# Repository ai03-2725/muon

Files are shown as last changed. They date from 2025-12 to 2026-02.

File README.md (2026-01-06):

# muon
Minimal USB-C to JST-SH daughterboard PCBs

**Currently in development; not finalized or tested.**

## Variants

### Variant A (latest revision A2)
Narrow and wide variant
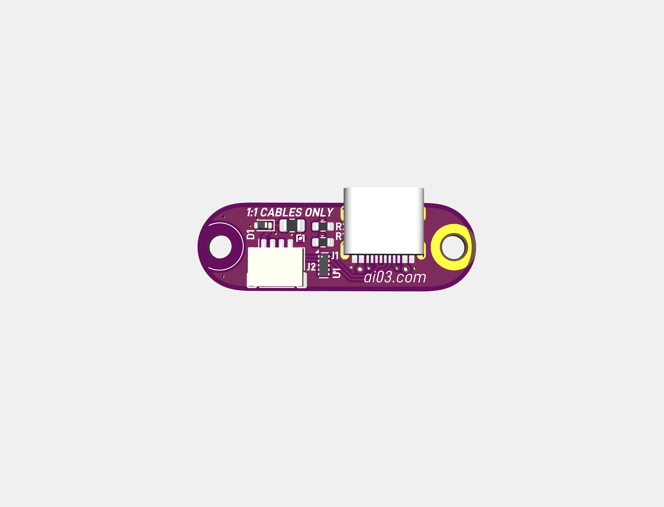
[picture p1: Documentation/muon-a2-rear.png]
Rear

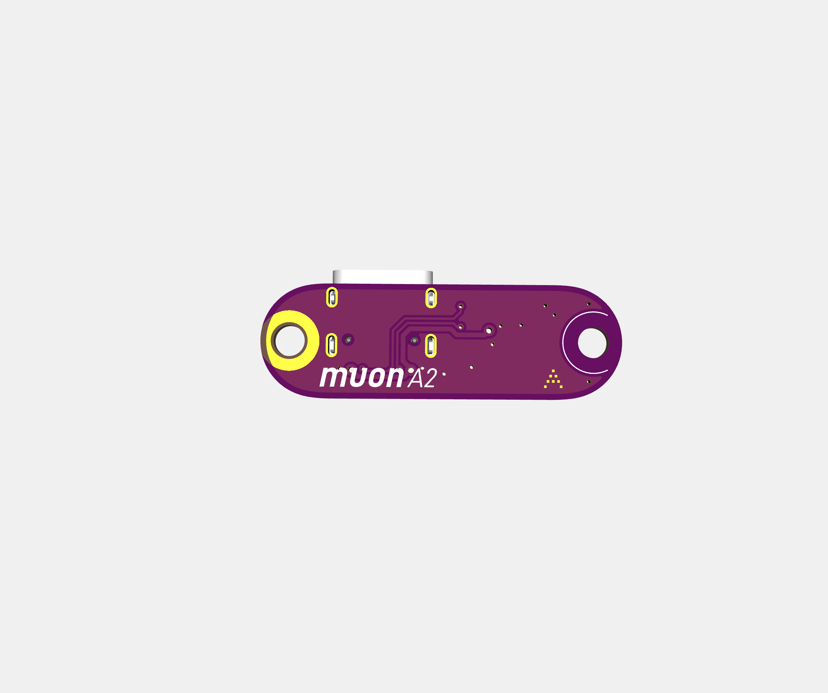
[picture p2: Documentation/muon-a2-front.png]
Front


### Variant B (latest revision B2)
Symmmetrical and rectangular variant
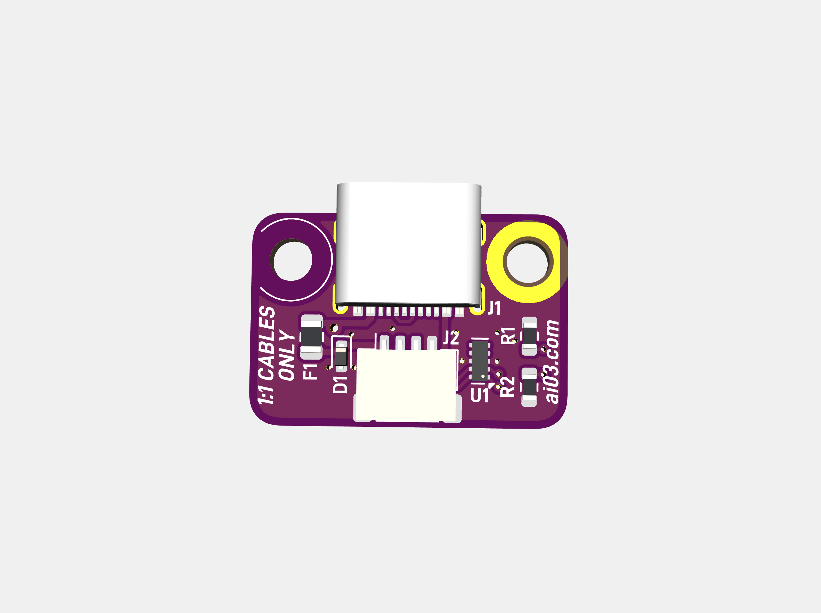
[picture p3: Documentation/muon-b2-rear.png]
Rear

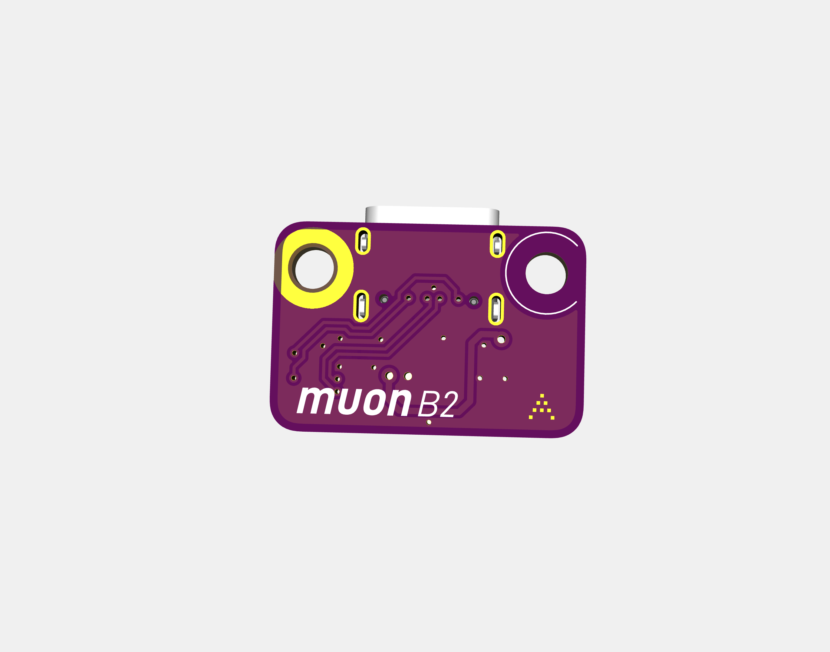
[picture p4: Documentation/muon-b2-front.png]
Front


## Features

- Physically compact
  - 31.50 x 10.00 mm for Variant A
  - 20.00 x 13.50 mm for Variant B
  - Balanced minimizing of dimensions with a focus on ease of implementation on the case-side
- Physically robust
  - 2x M2.5 screws for a balance between robustness, ease of manufacturing, user-friendliness, and physical compactness
  - 1.6mm PCB to counter cable torque and resist over-tensioned screw-in by users
- Minimal, practical implementation
  - Single-sided for easy assembly - whether at a factory or reflowing at home
  - Two-layer for affordable manufacturing
  - 3D printable solder paste stencil file included (0.2mm nozzle and line width, 0.08mm layer height)
  - Asymmetrical design with protruding USB port prevents accidental reverse installation by users
- Optimized for ease of case design
  - Straightforward, rational dimensions
  - Large USB connector overhang for case-side flexibility and robustness
  - Can be mounted component-side-up or component-side-down for prioritizing ease of servicing or physical compactness respectively  
  - 3D models and example case-side implementation provided (see the References folders in the Var-A/Var-B directories)
  - Designed with aesthetics in mind to avoid detracting from case visuals  
  - Example implementations can be CNC-machined with 2mm inner radius
- Proven circuitry and implementation based on the [Unified Daughterboard series](https://unified-daughterboard.github.io/#/)
  - ESD/overcurrent/overvoltage protection, single-path grounding of case via mounting screws
  - JST-SH connector with identical pinout to the Unified Daughterboard

## Dimensions
Mounting screws are M2.5.  
Only use flat screws - countersunk screws apply focused angled pressure on the screw holes and risk shattering the board apart.  
  
Recommended max diameter for screw heads/standoffs/mounting points contacting the board is 5.00mm centered on the mounting holes.  
Absolute max diameter is 6.0mm; ESD handling capabilities may be reduced when exceeding 5.00mm.  

### Variant A
Ends are roughly 5.00mm radius (slightly inset from a tangent arc for visual reasons).
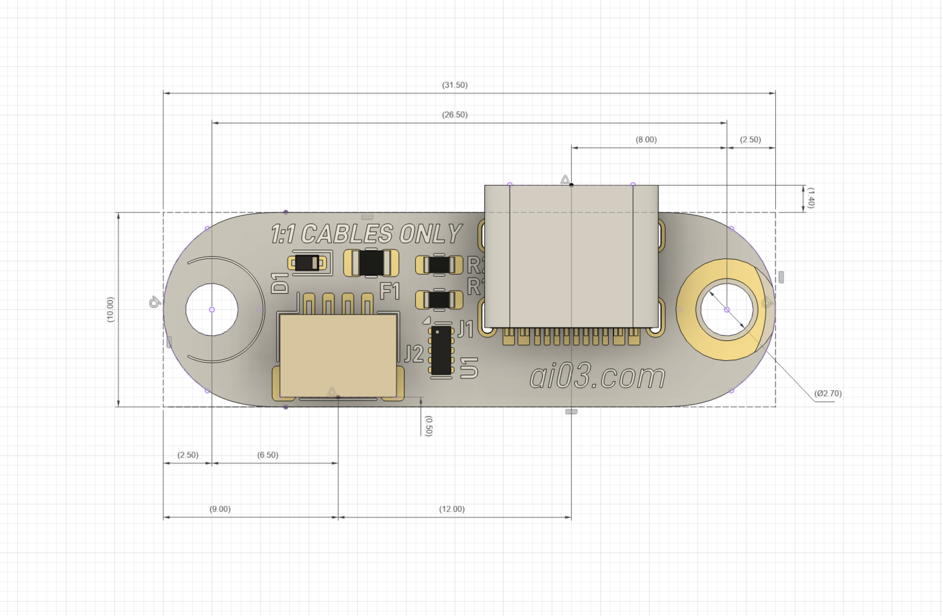
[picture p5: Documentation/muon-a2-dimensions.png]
Dimensions


### Variant B
Corners are roughly 1.85mm radius (slightly inset from a tangent arc for visual reasons).
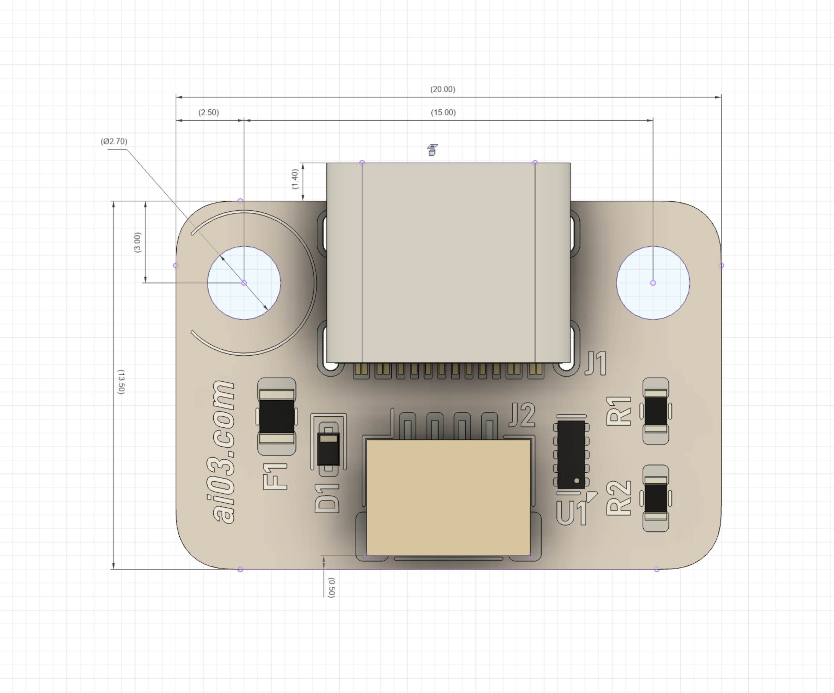
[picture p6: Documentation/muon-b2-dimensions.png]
Dimensions


## Pinout

Pinout is identical to the Unified Daughterboard series.  
Only use a one-to-one cable (the same type used on the Unified Daughterboard JST-type boards; pin 1 of one end maps to pin 1 of the other end).  

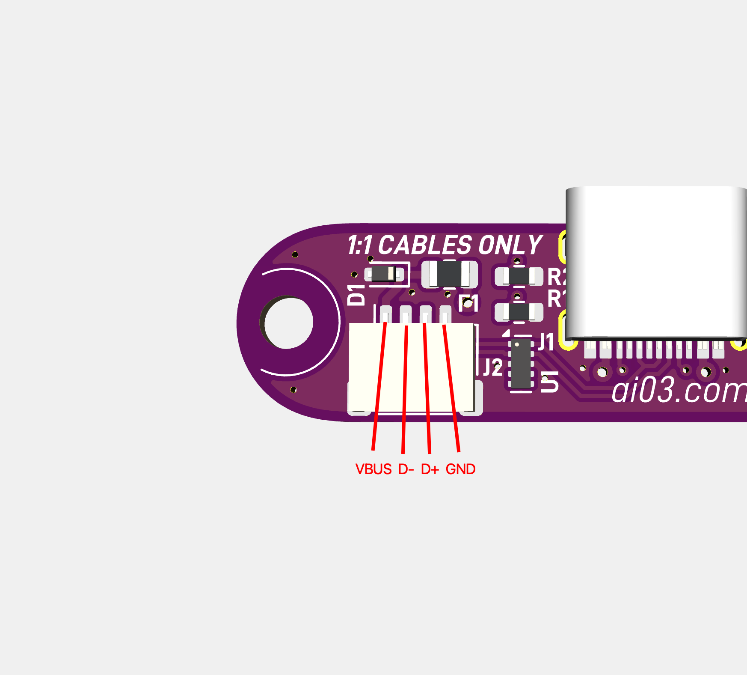
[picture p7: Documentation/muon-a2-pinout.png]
Pinout


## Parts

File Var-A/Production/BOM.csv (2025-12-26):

Reference | Qty | Value | Footprint | JLC Part Number
D1 | 1 | ESD5Z5V0 | Diode_SMD:D_SOD-523 | C727161
F1 | 1 | SMD0805-100-16 | Fuse:Fuse_0805_2012Metric | C968441
J1 | 1 | HRO_TYPE-C-31-M-12 | locallib:HRO-TYPE-C-31-M-12-Assembly | C165948
J2 | 1 | SM04B-SRSS-TB | Connector_JST:JST_SH_SM04B-SRSS-TB_1x04-1MP_P1.00mm_Horizontal | C160404
R1,R2 | 2 | 5.1k | Resistor_SMD:R_0603_1608Metric | C25905
U1 | 1 | TPD4E05U06DQA | Package_SON:USON-10_2.5x1.0mm_P0.5mm | C2836386

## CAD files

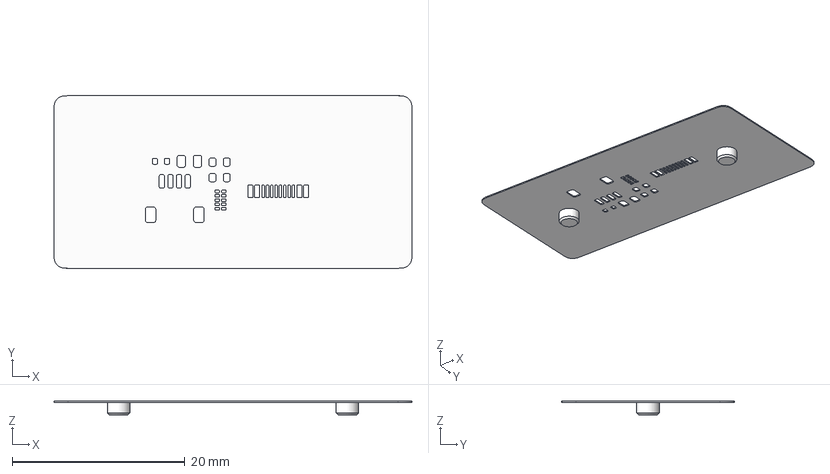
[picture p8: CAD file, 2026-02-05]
Var-A/Production/Stencil/muon-a2-stencil-3dp.step
41.5 x 20.0 x 1.60 mm

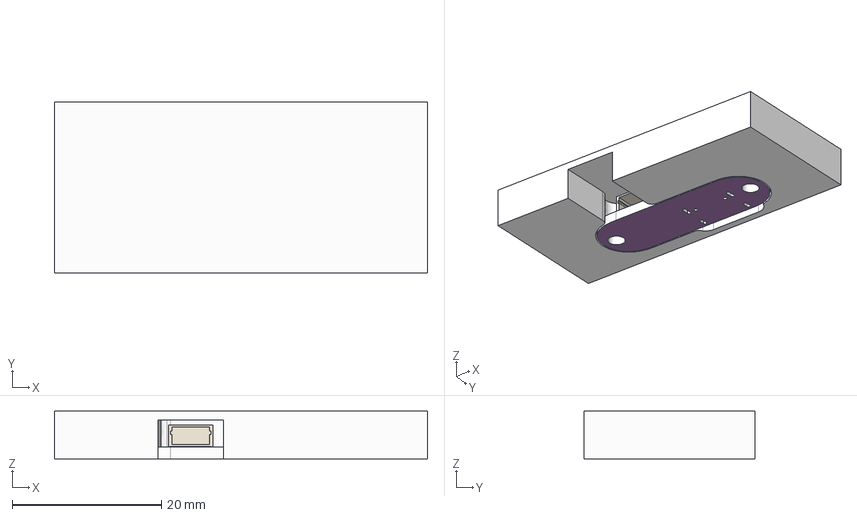
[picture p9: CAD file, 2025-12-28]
Var-A/References/muon-a2-Reference-Implementation.step
50.0 x 22.9 x 6.40 mm
Muon-Outline-1.6mm v1
R_0603_1608Metric x 2
kicad_embedded_212A95117681C903C141F67D1C4FB8A6
Fuse_0805_2012Metric
USON-10_2.5x1.0mm_P0.5mm
JST-SR-4
D_SOD-523

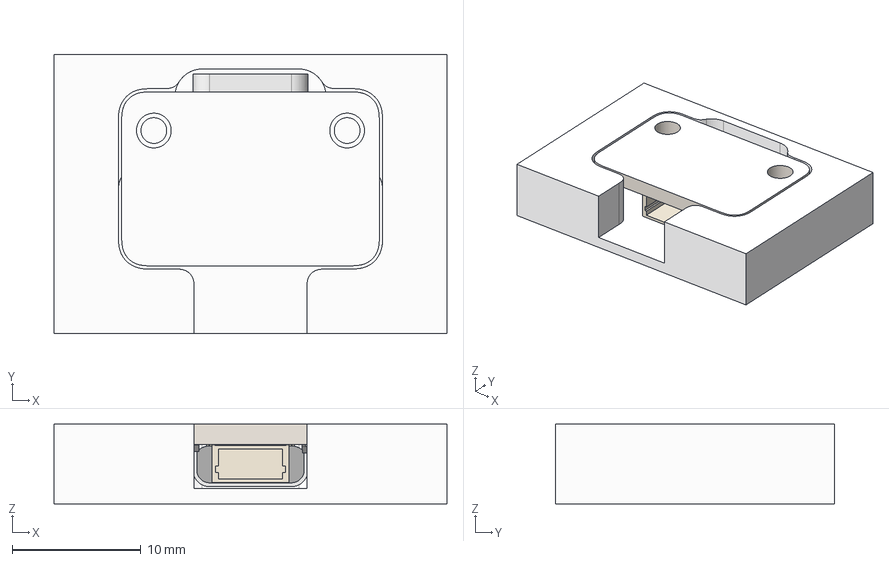
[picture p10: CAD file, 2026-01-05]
Var-B/References/muon-B2 Reference Implementation.step
30.5 x 21.6 x 6.20 mm
Muon-B-2 v19
USON-10_2.5x1.0mm_P0.5mm
D_SOD-523
kicad_embedded_212A95117681C903C141F67D1C4FB8A6
kicad_embedded_A277F6F4F07CA933ADDB95E0878375A1
Fuse_0805_2012Metric
R_0603_1608Metric x 2

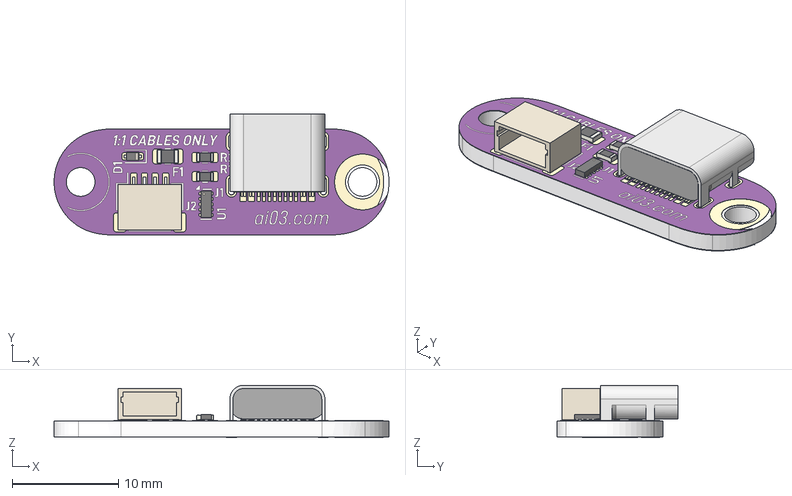
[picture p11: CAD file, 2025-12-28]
Var-A/References/muon-a2-3D-Detailed.step
31.5 x 11.4 x 4.93 mm
D_SOD-523
R_0603_1608Metric x 2
Fuse_0805_2012Metric
USON-10_2.5x1.0mm_P0.5mm
kicad_embedded_212A95117681C903C141F67D1C4FB8A6
JST-SR-4
muon_pad
muon_silkscreen
muon_silkscreen_1
muon_soldermask
muon_soldermask_1
Muon-Outline v5

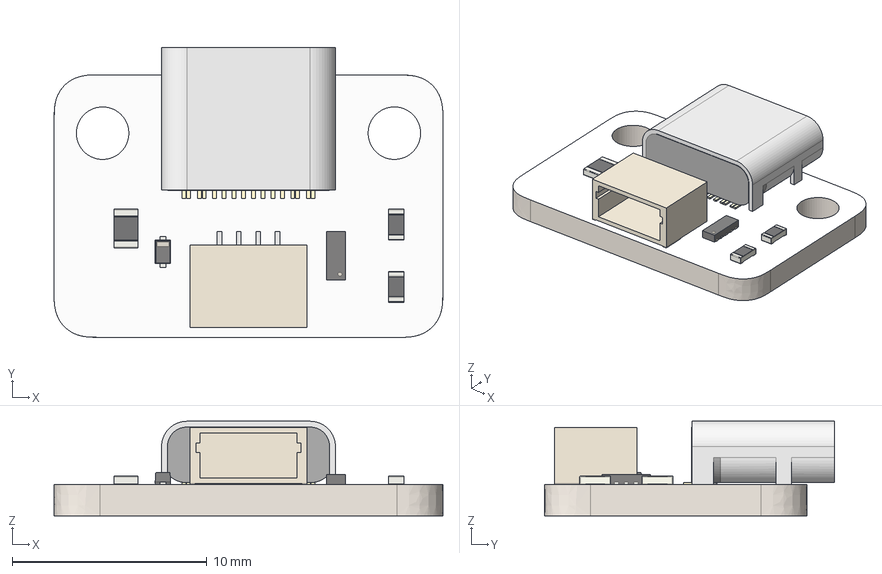
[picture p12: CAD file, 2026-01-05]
Var-B/References/muon-B2-3D-Simplified.step
20.0 x 14.9 x 4.86 mm
D_SOD-523
R_0603_1608Metric x 2
Fuse_0805_2012Metric
USON-10_2.5x1.0mm_P0.5mm
kicad_embedded_212A95117681C903C141F67D1C4FB8A6
kicad_embedded_A277F6F4F07CA933ADDB95E0878375A1
Muon-B-2 v19

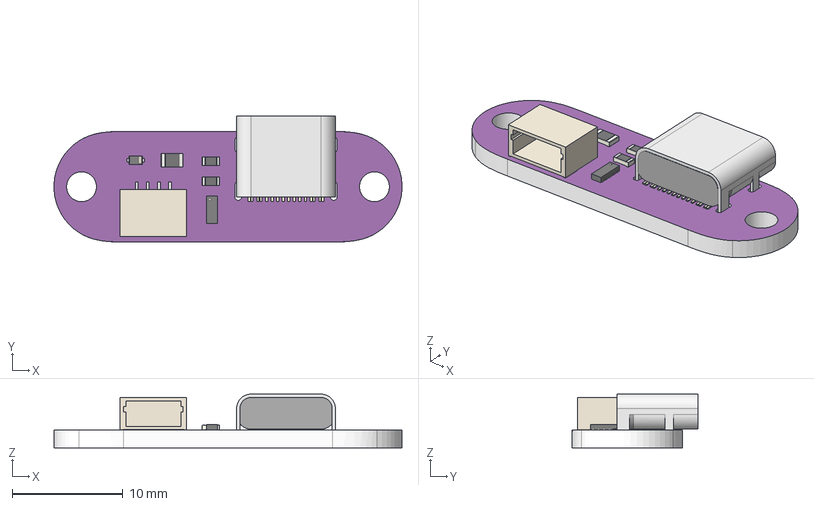
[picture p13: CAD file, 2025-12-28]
Var-A/References/muon-a2-3D-Simplified.step
31.5 x 11.4 x 4.86 mm
D_SOD-523
R_0603_1608Metric x 2
Fuse_0805_2012Metric
USON-10_2.5x1.0mm_P0.5mm
kicad_embedded_212A95117681C903C141F67D1C4FB8A6
JST-SR-4
Muon-Outline-1.6mm v1

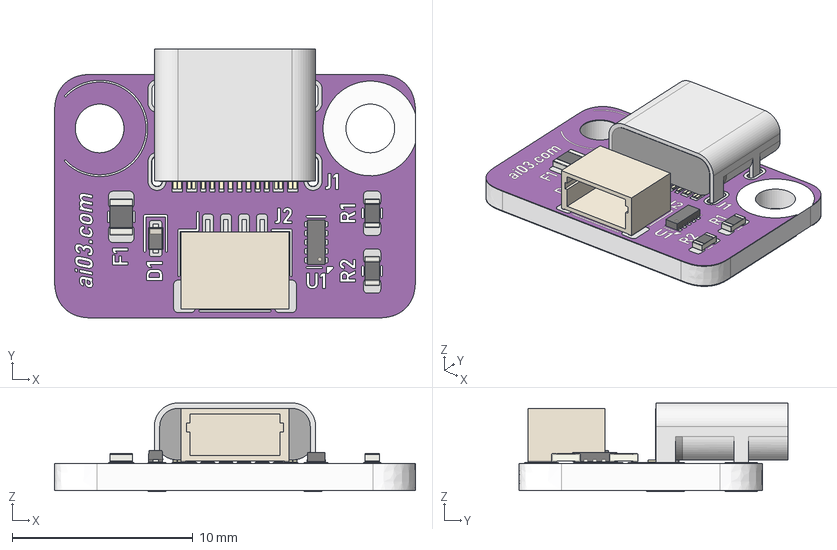
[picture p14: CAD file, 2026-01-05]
Var-B/References/muon-B2-3D-Detailed.step
20.0 x 14.9 x 4.93 mm
D_SOD-523
R_0603_1608Metric x 2
Fuse_0805_2012Metric
USON-10_2.5x1.0mm_P0.5mm
kicad_embedded_212A95117681C903C141F67D1C4FB8A6
kicad_embedded_A277F6F4F07CA933ADDB95E0878375A1
muon_pad
muon_silkscreen
muon_silkscreen_1
muon_soldermask
muon_soldermask_1
Muon-B-2 v19

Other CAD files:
References/muon-F_Paste.dxf
Var-A/Production/Stencil/muon-a2-F_Paste.dxf
Var-A/Production/Stencil/muon-a2-stencil-3dp.stl

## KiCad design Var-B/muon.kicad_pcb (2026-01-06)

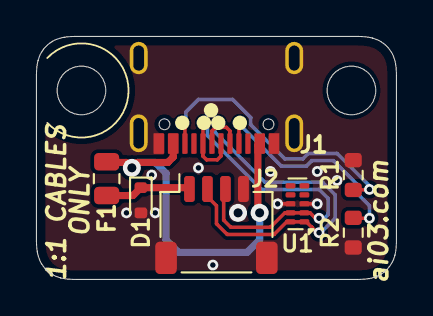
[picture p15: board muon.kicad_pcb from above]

Board: 2 copper layers, 20.0 x 13.5 mm, 9 parts (0 on the bottom side), 7 nets.

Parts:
D1: ESD5Z5V0; D_SOD-523
F1: SMD0805-100-16; Fuse_0805_2012Metric
J1: HRO_TYPE-C-31-M-12; HRO-TYPE-C-31-M-12-Assembly-Minimal
J2: SM04B-SRSS-TB; JST_SH_SM04B-SRSS-TB_1x04-1MP_P1.00mm_Horizontal_SmallerPads
MH1, MH2: Pad-M2.5; MountingHole-M2.5-Simple
R1, R2: 5.1k; R_0603_1608Metric
U1: TPD4E05U06DQA; USON-10_2.5x1.0mm_P0.5mm

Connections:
+5V: D1.1 (K), F1.2, J2.1
CC1: J1.A5 (CC1), R2.1
CC2: J1.B5 (CC2), R1.1
D+: J1.A6 (D+), J1.B6 (D+), J2.3, U1.2 (D1-)
D-: J1.A7 (D-), J1.B7 (D-), J2.2, U1.1 (D1+)
GND: D1.2 (A), J1.A1 (GND), J1.A12 (GND), J1.S1 (SHIELD), J2.4, J2.MP (MountPin), R1.2, R2.2, U1.3 (GND), U1.8 (GND)
VBUS: F1.1, J1.A4 (VBUS), J1.A9 (VBUS)

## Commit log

2025-12-28 Update to A2 revision
    [muon Example Implementation.step, muon-3D-Full.step, muon-3D-Simplified.step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]
2025-12-28 Add reference implementation
    [muon-a2-3D-Detailed.step, muon-a2-3D-Simplified.step, muon-a2-Reference-Implementation.step]
2025-12-28 Make B variant
    [BOM.csv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]
2025-12-28 Update A2 gerbers with new silkscreen
    [muon-B_Cu.gbl, muon-B_Mask.gbs, muon-B_Paste.gbp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]
2025-12-28 Add reference implementation for B
    [muon-b1 Reference Implementation.step]
2025-12-28 Update A gerbers with fixed USB-C footprint
    [muon-B_Cu.gbl, muon-B_Mask.gbs, muon-B_Paste.gbp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]
2026-01-05 Update B variant to B2
    [muon-B2-3D-Detailed.step, muon-B2-3D-Simplified.step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]
2026-01-05 Adjust silkscreen; update gerber
    [muon-B_Cu.gbl, muon-B_Mask.gbs, muon-B_Paste.gbp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]
2026-01-05 Adjust silkscreen
    [muon-B_Cu.gbl, muon-B_Mask.gbs, muon-B_Paste.gbp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]
2026-01-05 Add reference implementation for B2
    [muon-B2 Reference Implementation.step]
2026-01-06 Remove redundant silkscreen
    [muon-B_Cu.gbl, muon-B_Mask.gbs, muon-B_Paste.gbp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]
2026-02-05 Update stencils
    [muon-a2-stencil-3dp.step, muon-a2-stencil-3dp.stl, muon-a2-stencil.step]
